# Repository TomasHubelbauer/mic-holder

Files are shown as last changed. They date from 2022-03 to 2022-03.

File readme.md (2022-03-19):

# Microphone Holder

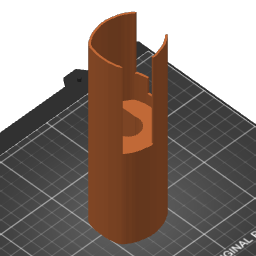
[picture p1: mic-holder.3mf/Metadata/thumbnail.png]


This repository hosts the OpenSCAD source code and related artifacts for a model
of a microphone holder that a Rode NT USB microphone can sit in.

The related artifacts include the STL as generated by OpenSCAD, the PrusaSlicer
project 3MF file extracted into a directory using https://hubelbauer.art/3mf and
the GCode generated by PrusaSlicer for my Prusa MK3S.

The 3MF is transformed manually prior to every commit by running:

```sh
curl hubelbauer.art/3mf -L | sh
```

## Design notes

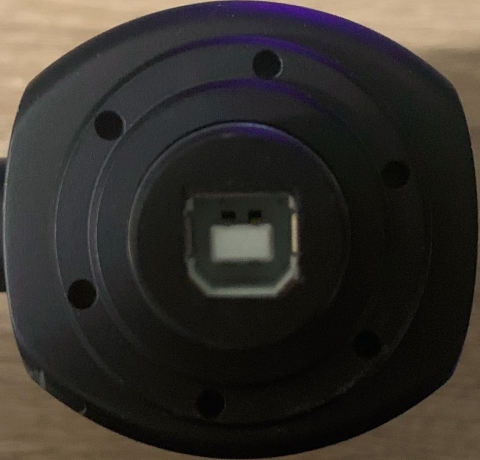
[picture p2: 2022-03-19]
mic-stand.png

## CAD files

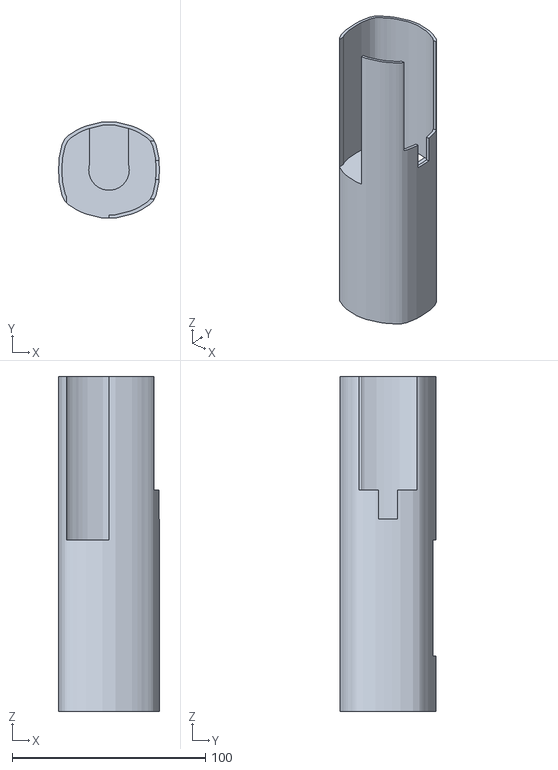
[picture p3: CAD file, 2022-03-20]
mic-holder.stl
52.0 x 49.8 x 173.2

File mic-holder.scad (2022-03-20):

// Photo of the botton of the mic used as a trace template
// Uncomment if tweaking tracing, otherwise leave be, the polygon is traced now.
// color("red")
// scale(.1)
// surface(file="mic-stand.png", center=true);

// Microphone bottom width
width = 48;

// Microphone bottom height
height = 46;

// The height of the mic holder
// Selected at this value so that the test print would surpass the protruding
// USB port and reach the bottom of the mic to be able to test fit the shape.
// 80 mm is the amount needed to reach the mid line around the mic.
size = 80;

// The thickness of the wall of the shape
thickness = 2;

// The amount of play to add between the mic and the holder
// This is here to ensure I can adjust the fit iteratively until I find a good
// value where the shell around the bottom of the mic is not stretched and thus
// stressed and structurally compromised but also not too loose not holding the
// mic well.
play = .25;

// The height of the stand part of the assembly
stand_depth = 80;

// A quarter of the blueprint of the mic bottom
// The blueprint has a symmetry which makes it so that we can mirror this twice
// and get the whole shape.
module a(size) {
  linear_extrude(size)
  polygon([
    [0, 0],
    [width / 2, 0],
    [width / 2, 2],
    [width / 2 - .1, 4],
    [width / 2 - .2, 6],
    [width / 2 - 1.5, 12],
    [width / 2 - 3, 15],
    [width / 2 - 4, 16],
    [width / 2 - 5.3, 17],
    [width / 2 - 7, 18],
    [width / 2 - 8.5, 19],
    [width / 2 - 10.5, 20],
    [width / 2 - 13, 21],
    [width / 2 - 17, 22],
    [width / 2 - 21, 23],
    [0, height / 2],
  ]);
}

// A half of the mic bottom blueprint
module b(size) {
  a(size);
  mirror([1, 0, 0]) a(size);
}

// The entirety of the mic bottom blueprint
module c(size) {
  b(size);
  mirror([0, 1, 0]) b(size);
}

// The scale by which to grow the outer shell to achieve a so-thick wall
// The calculation takes the size with the walls and divides it by the actual
// size producing the scale factor needed to raise the dimensions to grow to
// the larger size.
innerFactor = (width + play * 2) / width;
outerFactor = (width + play * 2 + thickness * 2) / (width + play * 2);

// The outer shell in which the microphone can sit snugly
difference() {
  union() {
    // The scaled version of the mic outline offset to make room for the walls
    scale(outerFactor)
    c(size);

    // The same shape in the other direction extending to be the stand column
    scale(outerFactor)
    translate([0, 0, -stand_depth])
    c(stand_depth);
  }

  // The internal unscaled mic outline shape removed to carve out the space
  translate([0, 0, thickness])
  scale([innerFactor, innerFactor, 1])
  c(thickness + size * outerFactor);

  // A hole for the USB connector protrusion to be able to get through
  translate([0, 0, -58])
  cylinder(60, 10.5, 10.5);

  translate([-10, 0, -58])
  cube([20, 40, 60]);

  // A cutout for the pop filter arm that wrap around the USB port protrusion
  translate([-width / 2 + thickness, -height, thickness])
  cube([width / 2 - thickness, height, thickness + size * outerFactor]);

  // A cutout for the control panel on the side of the mic (jack + knobs)
  translate([0, 5, thickness + 26]) cube([width, 10, size]);
  translate([0, -5, thickness + 11]) cube([width, 10, size]);
  translate([0, -15, thickness + 26]) cube([width, 10, size]);
}

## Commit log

2022-03-19 Commit the initial fit test version
    This version lacks a hole for the jack connector for monitoring as well as a cutout for the pop filter, that will come in case this model passes the fit test.
    [mic-holder.scad, mic-holder.stl]
2022-03-19 Add extra spacing and cutouts for controls and ports
    The fit that I had previously was too snug, the microphone would not slide all the way down. I am not sure if there is a slight taper on the body of the mic or if the PLA just accomodated some stretch and couldn't go further, but it was definitely too tight of a fit.
    I added some amount of play around the internal negative volume so that the microphone fits in better and also two cutouts. The pop filter arm cutout is extremely generous right now and I will eventually lock it down a bit. The one for knobs and the monitor jack matches the size of the side of the microphone and I think that one might look good lining the side so I might keep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
    [mic-holder.scad, mic-holder.stl]
2022-03-19 Decrease the play and make cutouts more precise
    .5 mm play seems like it is a nice fit, but maybe too lose. Let's try the middle between the zero it was before and the .5 mm it was now and see if it still fits.
    The knobs/jack cutout got raised to hold the wall together better and the amount is just enough to cover the mic bottom rounded edge, so it makes it nicer, too.
    The pop filter arm cutout was basically reduced by a half. The arm is 45 degrees I guess, because when positioned dead center in front of the arm, it works out nicely to half the front section leavin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
    [mic-holder.scad, mic-holder.stl]
2022-03-19 Fix the scaling of the negative volume to always cut out the top
    I forgot to scale the cutouts the same way the outer shell is scaled so the top returned when tweaking the size past a certain value. Scaling like this makes sure the relationship between the positive and negative meshes remains the same.
    [mic-holder.scad]
2022-03-19 Optimize the hole for the jack monitor connection
    I returned some of the shell back so that it is structurally more sound but still leaves enough room for the connector should I ever decide to use it.
    [mic-holder.scad]
2022-03-19 Extend the stand height and update the render
    For the two previous commits, I did not update the artifacts. With this one, which extends the stand below the surface so that the microphone can stand on its own, I am also updating the artifacts.
    [mic-holder.scad, mic-holder.stl]
2022-03-20 Extend shell and base height to potentially final dimensions
    The fit test went well and I think all of the cutouts are final as well now so let's do a test print with the final dimensions and in black PLA to see how the thing looks.
    [mic-holder.scad, mic-holder.stl]
